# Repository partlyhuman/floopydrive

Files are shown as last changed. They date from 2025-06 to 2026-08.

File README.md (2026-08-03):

# the Floopy Drive 💕

This is a flashcart/devcart for the Casio Loopy. 

[☕️ Pre-built carts shipping worldwide on loopy.land/shop](https://loopy.land/shop)

[📖 User's Guide](https://github.com/partlyhuman/loopycart/wiki)

[YouTube<br>📺 Introductory Video](http://www.youtube.com/watch?v=_Q8cJwyDRfA)

To help find your way around:

* [pcb/flash-32mbit/](pcb/flash-32mbit/) The star of the show, the Floopy Drive PCB
* [flash-programmer/](flash-programmer/) Firmware that runs on the Floopy Drive, plus the PC interface for flashing it
* [cart-shell/](cart-shell/) 3D printable case for the Floopy Drive
* [labels/](labels/) Printable labels you can affix to a finished Floopy Drive
* [pcb/](pcb/) Other boards built along the way include a reverse-engineered cart that started it all
* [scans/](scans/) Scans of de-populated OEM Loopy games used as reference
* [data/](data/) Archive of relevant part datasheets for quick reference

Related repositories:

* [OSCR](https://github.com/sanni/cartreader) — I contributed a Casio Loopy adapter and code to the Open Source Cartridge Dumper, as well as a [makeshift adapter](https://github.com/sanni/cartreader/discussions/354#discussioncomment-10103848) that doesn't require an original cart connector
* [Loopy-Tools](https://github.com/kasamikona/Loopy-Tools) — a treasure trove of documentation and tooling around the Loopy by @kasamikona
* [Loopy-Schematics](https://github.com/kasamikona/Loopy-Schematics) - Schematics for various parts of, and accessories for, the Casio Loopy by @kasamikona
* [LoopyMSE](https://github.com/LoopyMSE/LoopyMSE) — an open-source cross-platform Loopy emulator created by @PSI-Rockin

### Contributors! 💕

None of this would be possible without the contributions of [@kasamikona](https://github.com/kasamikona) and [@kvanderlaag](https://github.com/kvanderlaag), with many, many additional thanks to the members of the [Unloved Budget Computer Hole](https://discord.gg/DH8cArK2) Discord server.

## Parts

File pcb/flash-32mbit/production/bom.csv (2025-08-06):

Designator | Footprint | Quantity | Value | LCSC Part #
BT1 | Keystone-3034TR-MFG | 1 | CR2032
C1 | 0805 | 1 | 1u
C2, C4, C5, C6, C7 | 0805 | 5 | 0.1u
D1 | SOT-23 | 1 | BAT54C
D2 | SOT-23-3 | 1 | PMEG4005CT,215
D3 | SOT-23 | 1 | BSS138
J1 | LOOPY_Cart_Edge | 1 | ~
R1, R13, R2, R6, R9 | 0805 | 5 | 1K
R10 | 0805 | 1 | 2K2
R11, R14, R3, R4, R5, R8 | 0805 | 6 | 100K
R12 | 0805 | 1 | 10K
U1 | TSOP-I-56_18.4x14mm_P0.5mm-HandSolder | 1 | LH28F320SKTD-L70
U2 | SOIC127P1410X300-32N | 1 | AS6C1008-55SIN
U3 | SOT-23-5 | 1 | SN74LVC1G04
U4 | RP2040-Tiny | 1 | RP2040-Tiny
U5, U6, U7 | SSOP-28_5.3x10.2mm_P0.65mm | 3 | MCP23S17T-E/SS

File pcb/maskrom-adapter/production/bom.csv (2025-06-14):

Designator | Footprint | Quantity | Value | LCSC Part #
IC1 | LOOPY-SOIC-44 | 1 | Maskrom
IC2 | SOP50P2000X120-48N | 1 | M29F160FB5AN6F2
R1 | 0805 | 1 | 1K

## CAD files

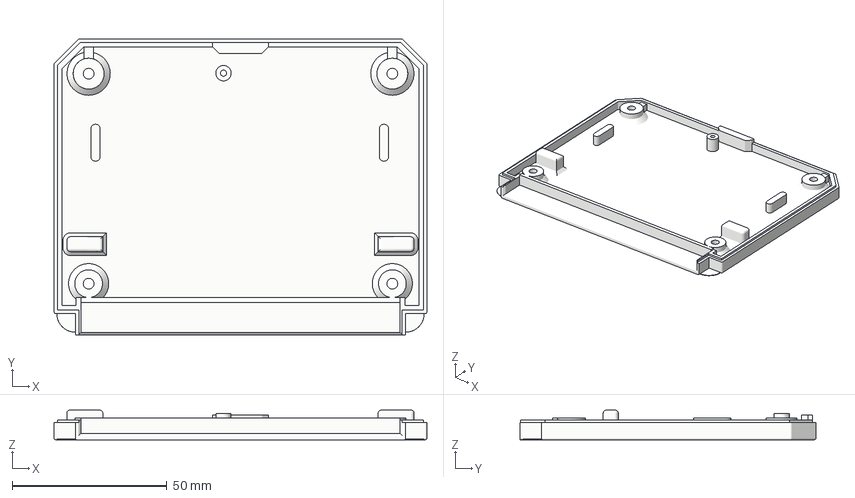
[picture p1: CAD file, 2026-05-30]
cart-shell/FloopyDrive-Rear.3mf
120.6 x 95.7 x 9.60 mm

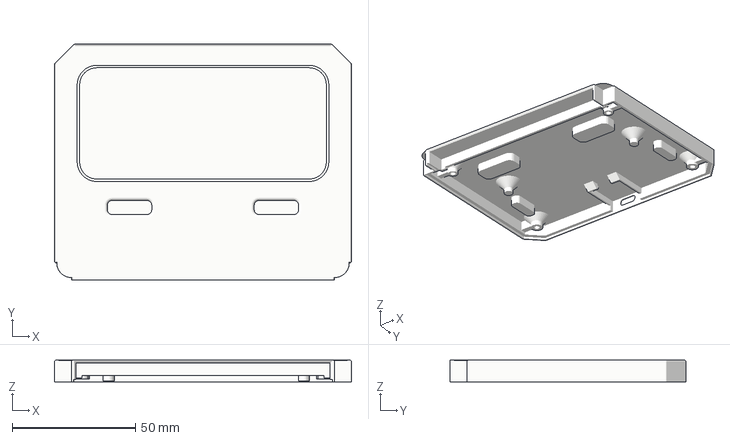
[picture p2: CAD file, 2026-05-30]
cart-shell/FloopyDrive-Front.3mf
120.6 x 95.7 x 8.85 mm

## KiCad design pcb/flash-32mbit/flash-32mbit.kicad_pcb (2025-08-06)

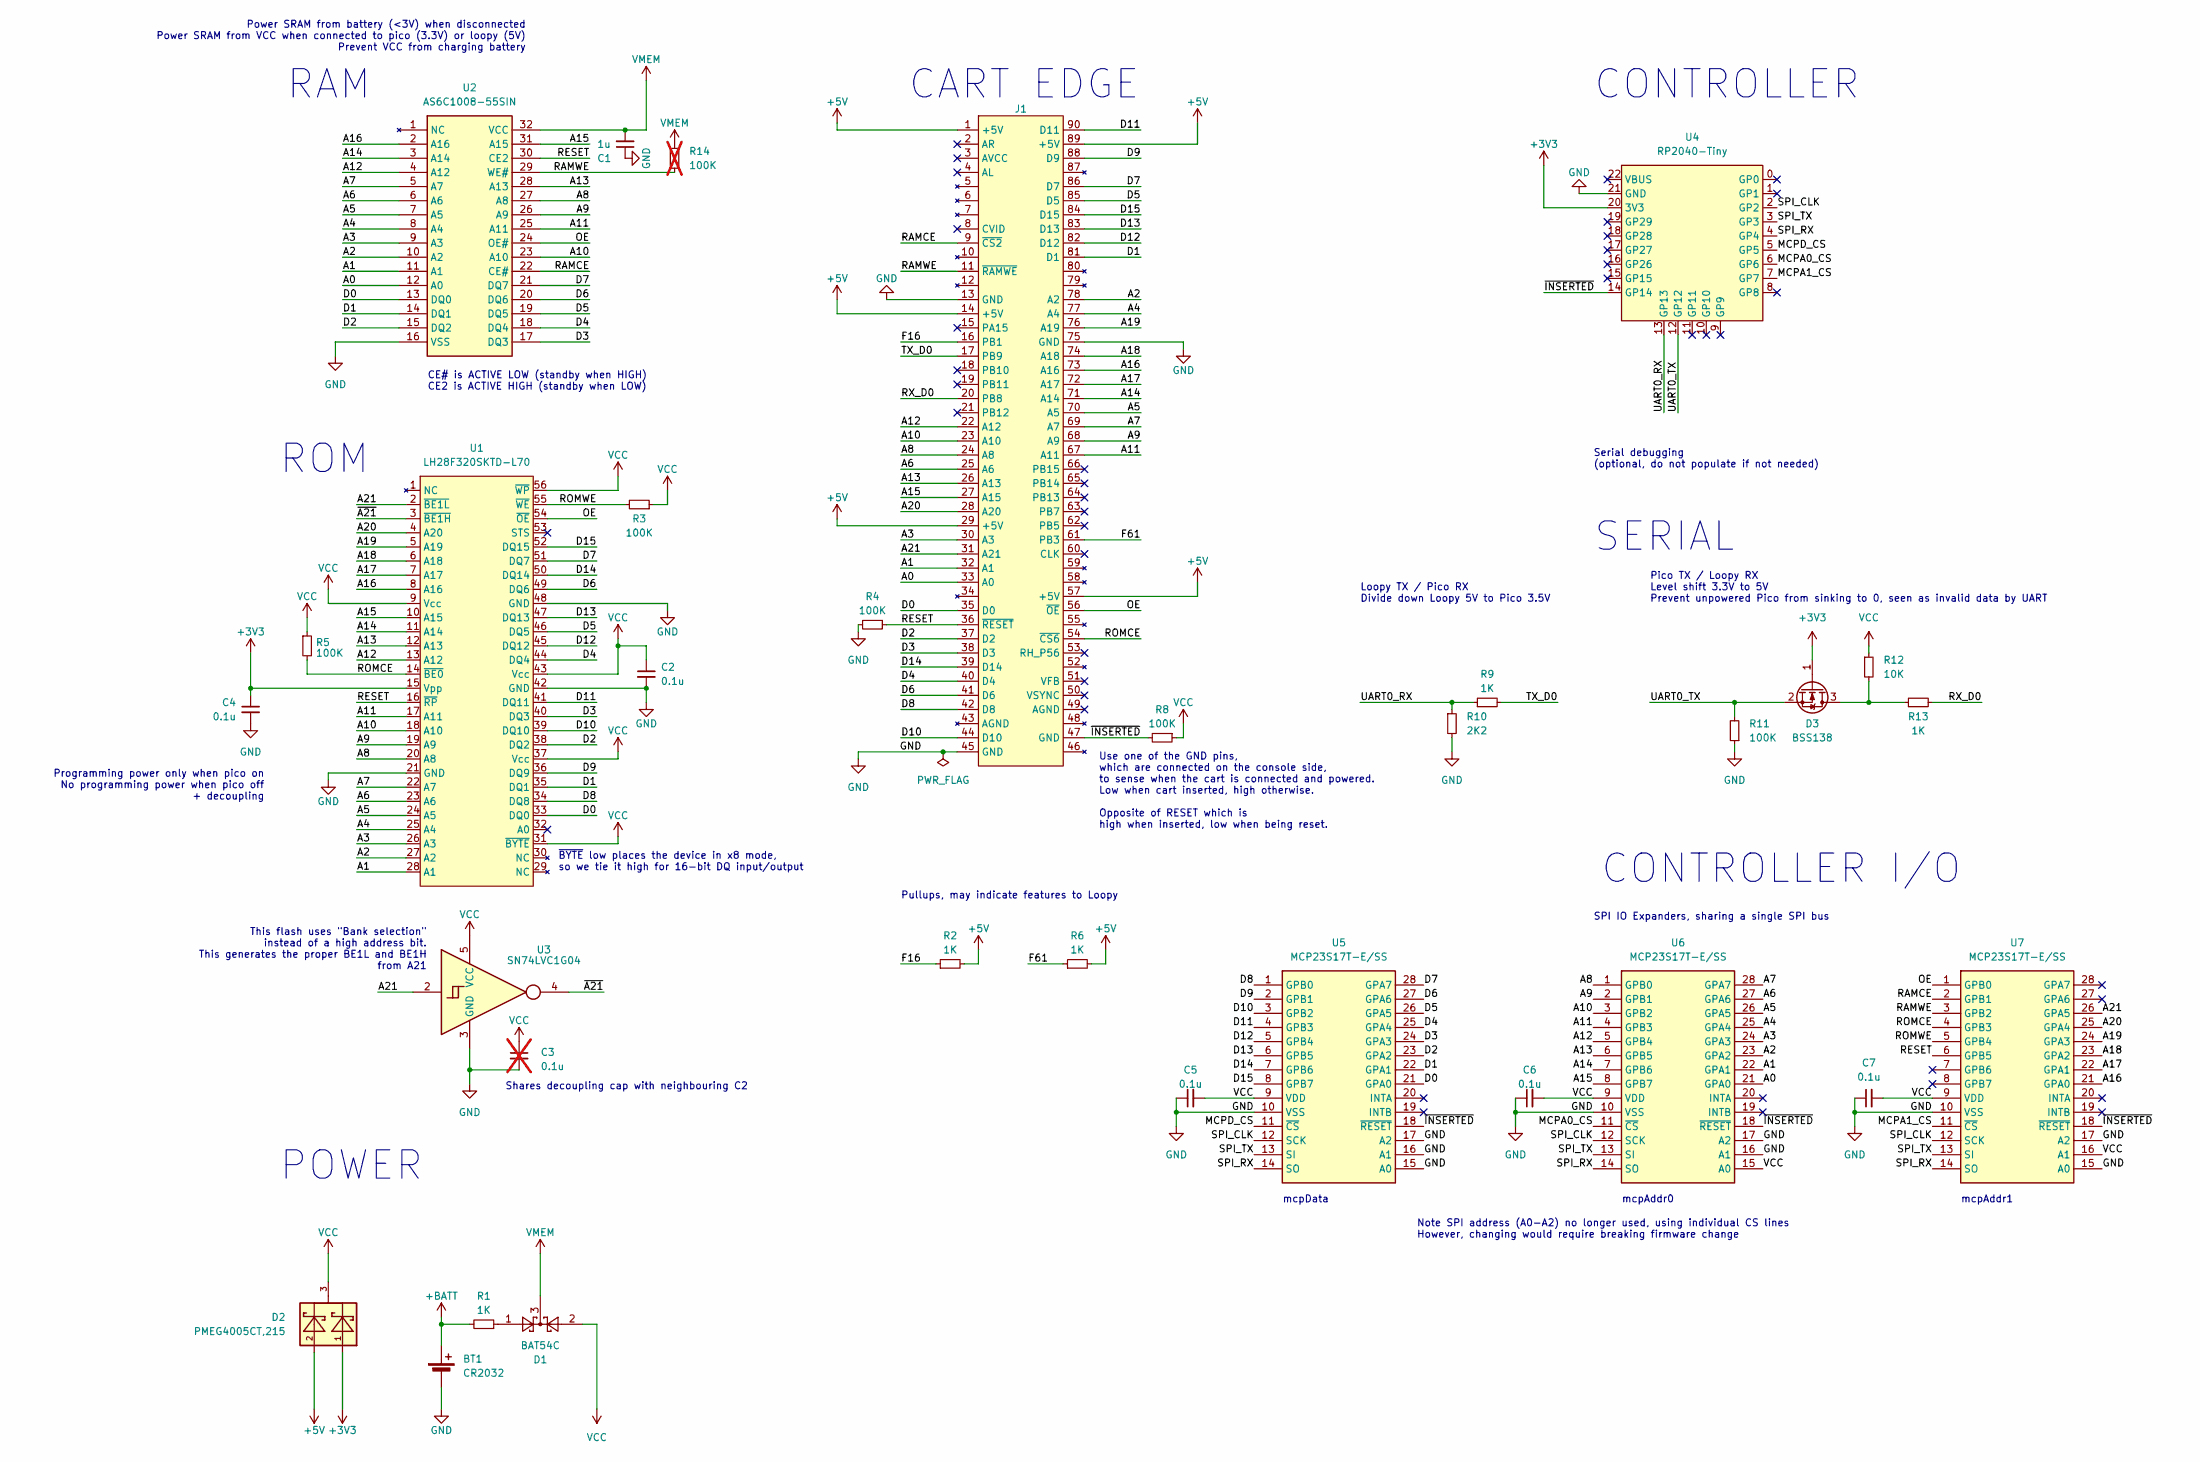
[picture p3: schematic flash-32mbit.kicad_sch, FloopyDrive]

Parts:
BT1: CR2032; Keystone-3034TR-MFG
C1: 1u; C_0805_2012Metric_Pad1.18x1.45mm_HandSolder
C2, C4, C5, C6, C7: 0.1u; C_0805_2012Metric_Pad1.18x1.45mm_HandSolder
C3: 0.1u; C_0805_2012Metric_Pad1.18x1.45mm_HandSolder; not fitted
D1: BAT54C; SOT-23
D2: PMEG4005CT,215; SOT-23-3
D3: BSS138; SOT-23
J1: LOOPY_Cart_Edge
R1, R2, R6, R9, R13: 1K; R_0805_2012Metric_Pad1.20x1.40mm_HandSolder
R3, R4, R5, R8, R11: 100K; R_0805_2012Metric_Pad1.20x1.40mm_HandSolder
R10: 2K2; R_0805_2012Metric_Pad1.20x1.40mm_HandSolder
R12: 10K; R_0805_2012Metric_Pad1.20x1.40mm_HandSolder
R14: 100K; R_0805_2012Metric_Pad1.20x1.40mm_HandSolder; not fitted
U1: LH28F320SKTD-L70; TSOP-I-56_18.4x14mm_P0.5mm-HandSolder
U2: AS6C1008-55SIN; SOIC127P1410X300-32N; Manufacturer_Part_Number AS6C1008-55SIN; Mouser Part Number 913-AS6C1008-55SIN
U3: SN74LVC1G04; SOT-23-5
U4: RP2040-Tiny
U5, U6, U7: MCP23S17T-E/SS; SSOP-28_5.3x10.2mm_P0.65mm; Manufacturer_Part_Number MCP23S17T-E/SO; Mouser Part Number 579-MCP23S17T-E/SO

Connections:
+3V3: C4.1, D2.1, D3.1 (G), U1.15 (Vpp), U4.20 (3V3)
+5V: D2.2, J1.1 (+5V), J1.14 (+5V), J1.29 (+5V), J1.57 (+5V), J1.89 (+5V), R2.2, R6.2
+BATT: BT1.1 (+), R1.2
/A0: J1.33 (A0), U2.12 (A0), U6.21 (GPA0)
/A1: J1.32 (A1), U1.28 (A1), U2.11 (A1), U6.22 (GPA1)
/A2: J1.78 (A2), U1.27 (A2), U2.10 (A2), U6.23 (GPA2)
/A3: J1.30 (A3), U1.26 (A3), U2.9 (A3), U6.24 (GPA3)
/A4: J1.77 (A4), U1.25 (A4), U2.8 (A4), U6.25 (GPA4)
/A5: J1.70 (A5), U1.24 (A5), U2.7 (A5), U6.26 (GPA5)
/A6: J1.25 (A6), U1.23 (A6), U2.6 (A6), U6.27 (GPA6)
/A7: J1.69 (A7), U1.22 (A7), U2.5 (A7), U6.28 (GPA7)
/A8: J1.24 (A8), U1.20 (A8), U2.27 (A8), U6.1 (GPB0)
/A9: J1.68 (A9), U1.19 (A9), U2.26 (A9), U6.2 (GPB1)
/A10: J1.23 (A10), U1.18 (A10), U2.23 (A10), U6.3 (GPB2)
/A11: J1.67 (A11), U1.17 (A11), U2.25 (A11), U6.4 (GPB3)
/A12: J1.22 (A12), U1.13 (A12), U2.4 (A12), U6.5 (GPB4)
/A13: J1.26 (A13), U1.12 (A13), U2.28 (A13), U6.6 (GPB5)
/A14: J1.71 (A14), U1.11 (A14), U2.3 (A14), U6.7 (GPB6)
/A15: J1.27 (A15), U1.10 (A15), U2.31 (A15), U6.8 (GPB7)
/A16: J1.73 (A16), U1.8 (A16), U2.2 (A16), U7.21 (GPA0)
/A17: J1.72 (A17), U1.7 (A17), U7.22 (GPA1)
/A18: J1.74 (A18), U1.6 (A18), U7.23 (GPA2)
/A19: J1.76 (A19), U1.5 (A19), U7.24 (GPA3)
/A20: J1.28 (A20), U1.4 (A20), U7.25 (GPA4)
/A21: J1.31 (A21), U1.2 (~BE1L), U3.2, U7.26 (GPA5)
/D0: J1.35 (D0), U1.33 (DQ0), U2.13 (DQ0), U5.21 (GPA0)
/D1: J1.81 (D1), U1.35 (DQ1), U2.14 (DQ1), U5.22 (GPA1)
/D2: J1.37 (D2), U1.38 (DQ2), U2.15 (DQ2), U5.23 (GPA2)
/D3: J1.38 (D3), U1.40 (DQ3), U2.17 (DQ3), U5.24 (GPA3)
/D4: J1.40 (D4), U1.44 (DQ4), U2.18 (DQ4), U5.25 (GPA4)
/D5: J1.85 (D5), U1.46 (DQ5), U2.19 (DQ5), U5.26 (GPA5)
/D6: J1.41 (D6), U1.49 (DQ6), U2.20 (DQ6), U5.27 (GPA6)
/D7: J1.86 (D7), U1.51 (DQ7), U2.21 (DQ7), U5.28 (GPA7)
/D8: J1.42 (D8), U1.34 (DQ8), U5.1 (GPB0)
/D9: J1.88 (D9), U1.36 (DQ9), U5.2 (GPB1)
/D10: J1.44 (D10), U1.39 (DQ10), U5.3 (GPB2)
/D11: J1.90 (D11), U1.41 (DQ11), U5.4 (GPB3)
/D12: J1.82 (D12), U1.45 (DQ12), U5.5 (GPB4)
/D13: J1.83 (D13), U1.47 (DQ13), U5.6 (GPB5)
/D14: J1.39 (D14), U1.50 (DQ14), U5.7 (GPB6)
/D15: J1.84 (D15), U1.52 (DQ15), U5.8 (GPB7)
/F16: J1.16 (PB1), R2.1
/F61: J1.61 (PB3), R6.1
/MCPA0_CS: U4.6 (GP6), U6.11 (~CS)
/MCPA1_CS: U4.7 (GP7), U7.11 (~CS)
/MCPD_CS: U4.5 (GP5), U5.11 (~CS)
/OE: J1.56 (~OE), U1.54 (~OE), U2.24 (OE#), U7.1 (GPB0)
/RAMCE: J1.9 (~CS2), U2.22 (CE#), U7.2 (GPB1)
/RAMWE: J1.11 (~RAMWE), R14.2, U2.29 (WE#), U7.3 (GPB2)
/RESET: J1.36 (~RESET), R4.1, U1.16 (~RP), U2.30 (CE2), U7.6 (GPB5)
/ROMCE: J1.54 (~CS6), R5.2, U1.14 (~BE0), U7.4 (GPB3)
/ROMWE: R3.2, U1.55 (~WE), U7.5 (GPB4)
/RX_D0: J1.20 (PB8), R13.2
/SPI_CLK: U4.2 (GP2), U5.12 (SCK), U6.12 (SCK), U7.12 (SCK)
/SPI_RX: U4.4 (GP4), U5.14 (SO), U6.14 (SO), U7.14 (SO)
/SPI_TX: U4.3 (GP3), U5.13 (SI), U6.13 (SI), U7.13 (SI)
/TX_D0: J1.17 (PB9), R9.2
/UART0_RX: R9.1, R10.1, U4.13 (GP13)
/UART0_TX: D3.2 (S), R11.2, U4.12 (GP12)
/~A21: U1.3 (~BE1H), U3.4
/~INSERTED: J1.47 (GND), R8.2, U4.14 (GP14), U5.18 (~RESET), U6.18 (~RESET), U7.18 (~RESET)
GND: BT1.2 (-), C1.1, C2.2, C3.2, C4.2, C5.1, C6.1, C7.1, J1.13 (GND), J1.45 (GND), J1.75 (GND), R4.2, R10.2, R11.1, U1.21 (GND), U1.42 (GND), U1.48 (GND), U2.16 (VSS), U3.3 (GND), U4.21 (GND), U5.10 (VSS), U5.15 (A0), U5.16 (A1), U5.17 (A2), U6.10 (VSS), U6.16 (A1), U6.17 (A2), U7.10 (VSS), U7.15 (A0), U7.17 (A2)
unnamed: D1.1, R1.1
unnamed: D3.3 (D), R12.2, R13.1
VCC: C2.1, C3.1, C5.2, C6.2, C7.2, D1.2, D2.3, R3.1, R5.1, R8.1, R12.1, U1.9 (Vcc), U1.31 (~BYTE), U1.37 (Vcc), U1.43 (Vcc), U1.56 (~WP), U3.5 (VCC), U5.9 (VDD), U6.9 (VDD), U6.15 (A0), U7.9 (VDD), U7.16 (A1)
VMEM: C1.2, D1.3, R14.1, U2.32 (VCC)

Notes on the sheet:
Use one of the GND pins, which are connected on the console side, to sense when the cart is connected and powered. Low when cart inserted, high otherwise. Opposite of RESET which is high when inserted, low when being reset.
Power SRAM from battery (<3V) when disconnected Power SRAM from VCC when connected to pico (3.3V) or loopy (5V) Prevent VCC from charging battery
POWER
RAM
Shares decoupling cap with neighbouring C2
ROM
Loopy TX / Pico RX Divide down Loopy 5V to Pico 3.5V
CE# is ACTIVE LOW (standby when HIGH) CE2 is ACTIVE HIGH (standby when LOW)
Note SPI address (A0-A2) no longer used, using individual CS lines However, changing would require breaking firmware change
CART EDGE
mcpAddr0
mcpAddr1
This flash uses "Bank selection" instead of a high address bit. This generates the proper BE1L and BE1H from A21
Programming power only when pico on No programming power when pico off + decoupling
Pullups, may indicate features to Loopy
Serial debugging (optional, do not populate if not needed)
Pico TX / Loopy RX Level shift 3.3V to 5V Prevent unpowered Pico from sinking to 0, seen as invalid data by UART
SERIAL
SPI IO Expanders, sharing a single SPI bus
~{BYTE} low places the device in x8 mode, so we tie it high for 16-bit DQ input/output
CONTROLLER
CONTROLLER I/O
mcpData

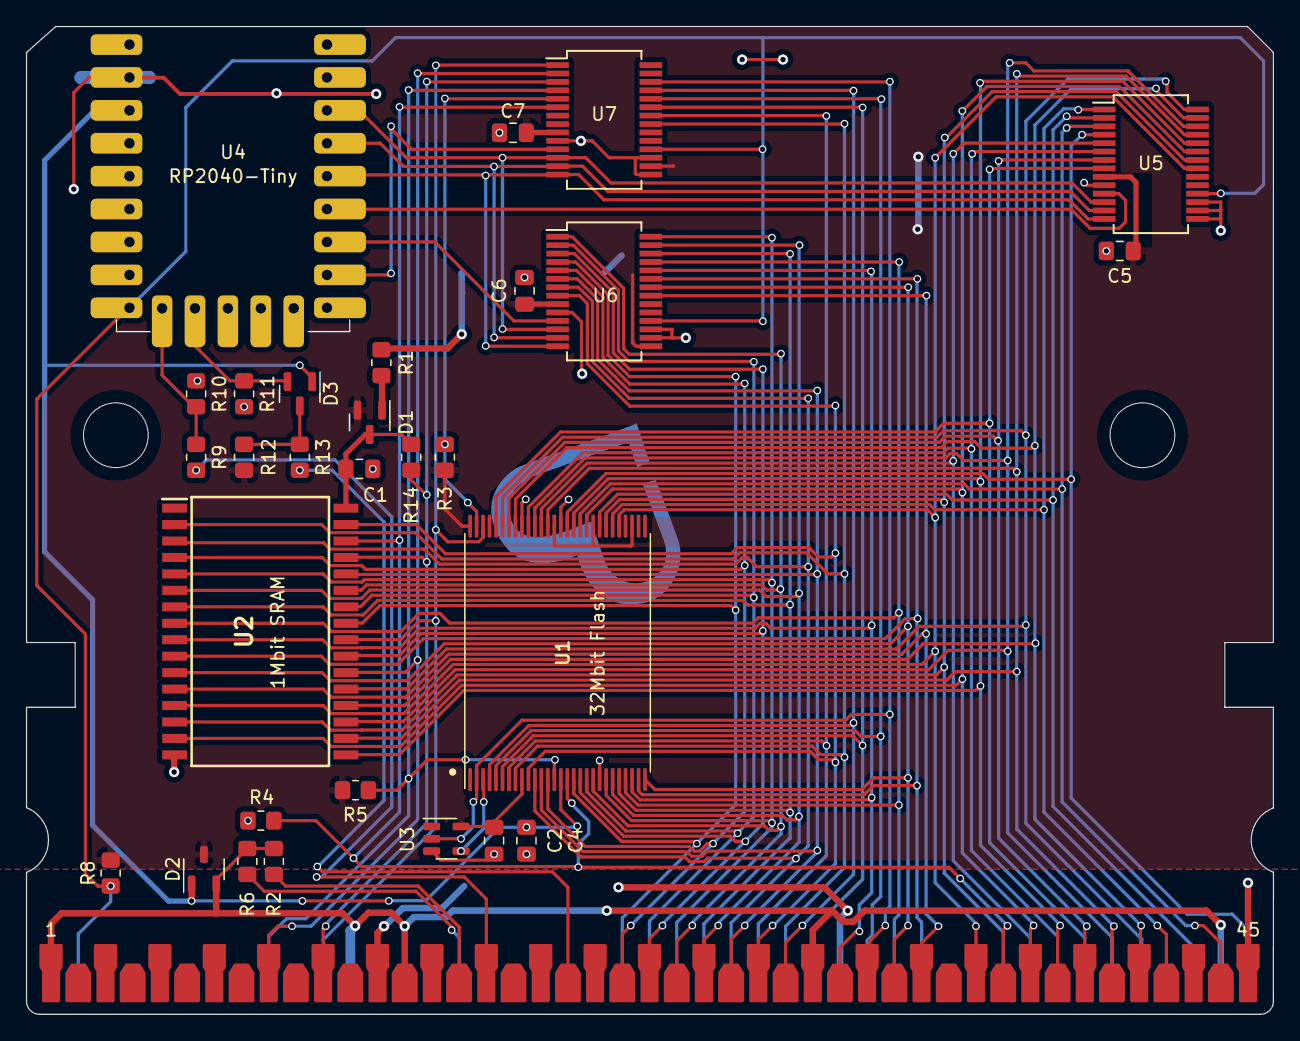
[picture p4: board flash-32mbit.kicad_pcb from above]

Board: 2 copper layers, 96.3 x 76.2 mm, 33 parts (1 on the bottom side), 66 nets.

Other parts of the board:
H1, H2: MountingHole_5mm

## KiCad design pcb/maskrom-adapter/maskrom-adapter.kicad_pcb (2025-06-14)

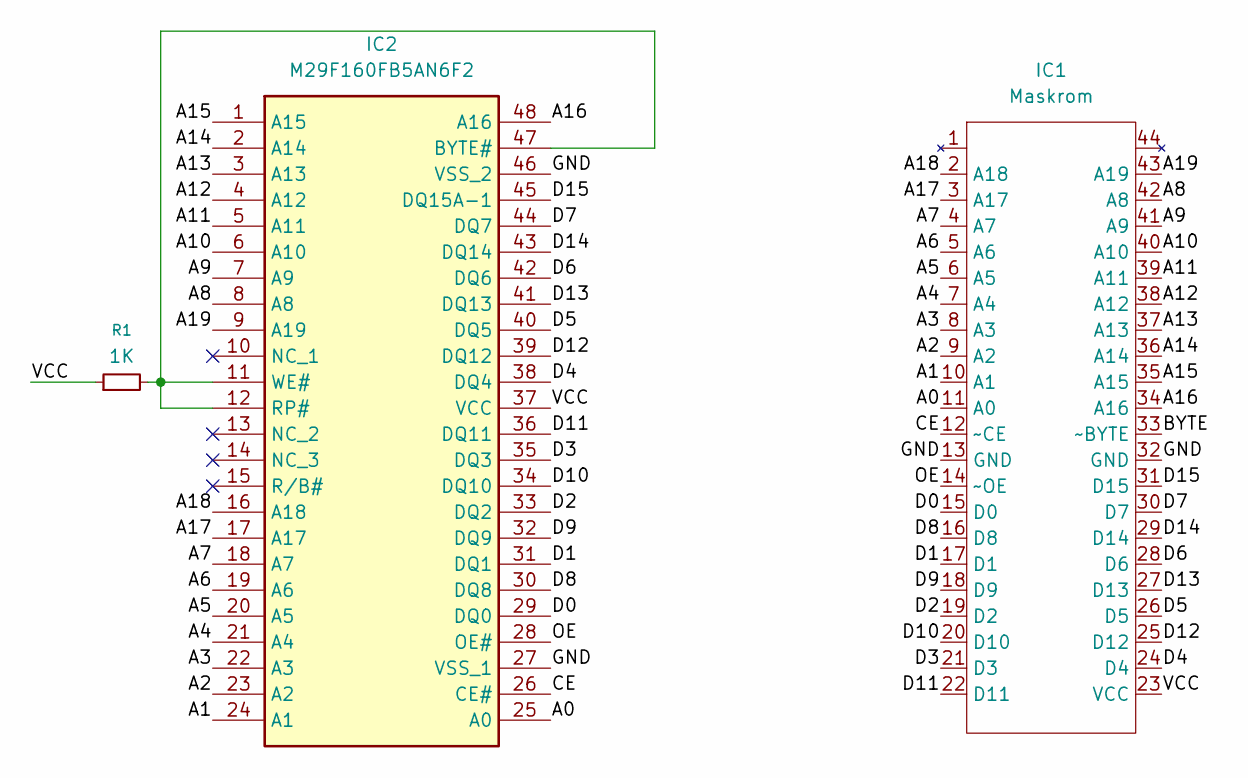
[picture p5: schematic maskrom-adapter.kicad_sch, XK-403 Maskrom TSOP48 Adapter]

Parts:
IC1: Maskrom; LOOPY-SOIC-44
IC2: M29F160FB5AN6F2; SOP50P2000X120-48N; Manufacturer_Part_Number M29F160FB5AN6F2; Mouser Part Number 913-M29F160FB5AN6F2
R1: 1K; LED_0805_2012Metric_Pad1.15x1.40mm_HandSolder

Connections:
/A0: IC1.11 (A0), IC2.25 (A0)
/A1: IC1.10 (A1), IC2.24 (A1)
/A2: IC1.9 (A2), IC2.23 (A2)
/A3: IC1.8 (A3), IC2.22 (A3)
/A4: IC1.7 (A4), IC2.21 (A4)
/A5: IC1.6 (A5), IC2.20 (A5)
/A6: IC1.5 (A6), IC2.19 (A6)
/A7: IC1.4 (A7), IC2.18 (A7)
/A8: IC1.42 (A8), IC2.8 (A8)
/A9: IC1.41 (A9), IC2.7 (A9)
/A10: IC1.40 (A10), IC2.6 (A10)
/A11: IC1.39 (A11), IC2.5 (A11)
/A12: IC1.38 (A12), IC2.4 (A12)
/A13: IC1.37 (A13), IC2.3 (A13)
/A14: IC1.36 (A14), IC2.2 (A14)
/A15: IC1.35 (A15), IC2.1 (A15)
/A16: IC1.34 (A16), IC2.48 (A16)
/A17: IC1.3 (A17), IC2.17 (A17)
/A18: IC1.2 (A18), IC2.16 (A18)
/A19: IC1.43 (A19), IC2.9 (A19)
/BYTE: IC1.33 (~BYTE)
/CE: IC1.12 (~CE), IC2.26 (CE#)
/D0: IC1.15 (D0), IC2.29 (DQ0)
/D1: IC1.17 (D1), IC2.31 (DQ1)
/D2: IC1.19 (D2), IC2.33 (DQ2)
/D3: IC1.21 (D3), IC2.35 (DQ3)
/D4: IC1.24 (D4), IC2.38 (DQ4)
/D5: IC1.26 (D5), IC2.40 (DQ5)
/D6: IC1.28 (D6), IC2.42 (DQ6)
/D7: IC1.30 (D7), IC2.44 (DQ7)
/D8: IC1.16 (D8), IC2.30 (DQ8)
/D9: IC1.18 (D9), IC2.32 (DQ9)
/D10: IC1.20 (D10), IC2.34 (DQ10)
/D11: IC1.22 (D11), IC2.36 (DQ11)
/D12: IC1.25 (D12), IC2.39 (DQ12)
/D13: IC1.27 (D13), IC2.41 (DQ13)
/D14: IC1.29 (D14), IC2.43 (DQ14)
/D15: IC1.31 (D15), IC2.45 (DQ15A-1)
/GND: IC1.13 (GND), IC1.32 (GND), IC2.27 (VSS_1), IC2.46 (VSS_2)
/OE: IC1.14 (~OE), IC2.28 (OE#)
/VCC: IC1.23 (VCC), IC2.37 (VCC), R1.1
unnamed: IC2.11 (WE#), IC2.12 (RP#), IC2.47 (BYTE#), R1.2

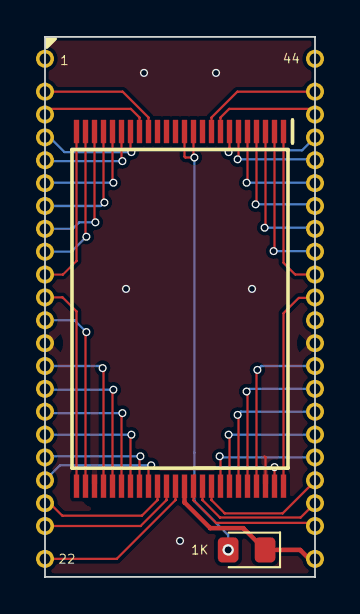
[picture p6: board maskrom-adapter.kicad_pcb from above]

Board: 2 copper layers, 15.0 x 30.0 mm, 3 parts (0 on the bottom side), 41 nets.

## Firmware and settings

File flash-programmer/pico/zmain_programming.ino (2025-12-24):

#define ABORT_AFTER_MS 1000

// Keep Adafruit VID, custom PID for programming
#define VID_PROG 0x239A
#define PID_PROG 0xF100

static int bootErrors = 0;

void onSuccess(bool echoOk = true) {
  if (echoOk) echo_ok();
  setControl(IDLE);
  ledColor(0);
}

void loop_programming() {
  static uint8_t buf[USB_BUFSIZE];
  static bool isProgrammingFlash = false;
  static bool isProgrammingSram = false;
  static uint32_t addr = 0;
  static uint32_t totalBytes;
  static uint32_t idleSince = 0;


  if (!usb_web.available()) {
    // DEBUGGING idle detect shows the pico is still looping if other things have halted due to error
    if (idleSince == 0) {
      idleSince = millis();
    } else if (millis() - idleSince > ABORT_AFTER_MS) {
      if (isProgrammingFlash || isProgrammingSram) {
        isProgrammingFlash = false;
        isProgrammingSram = false;
        echo_all("!ERROR Aborted programming after no data\r\n");
      }
    }
    return;
  }
  idleSince = 0;

  size_t bufLen = usb_web.read(buf, USB_BUFSIZE);

  if (isProgrammingFlash) {
    isProgrammingFlash = flashWriteBuffer(buf, bufLen, addr, totalBytes);
    if (!isProgrammingFlash) onSuccess();
    return;
  } else if (isProgrammingSram) {
    isProgrammingSram = sramWriteBuffer(buf, bufLen, addr, totalBytes);
    if (!isProgrammingSram) onSuccess();
    return;
  }

  else if (buf[0] == 'E') {
    // ERASE COMMAND
    if (buf[1] == '\r') {
      ledColor(BLUE);
      flashCommand(0, CMD_RESET);
      delay(100);
      flashClearLocks();
      delay(100);
      flashCommand(0, CMD_RESET);
      delay(100);
      flashEraseAll();
      delay(100);
      flashCommand(0, CMD_RESET);
      onSuccess();
    } else if (buf[1] == 's' && buf[2] == '\r') {
      ledColor(BLUE);
      sramErase();
      onSuccess();
    } else if (buf[1] == '0' && buf[2] == '\r') {
      // DEPRECATED
      ledColor(BLUE);
      flashEraseBank(0);
      flashCommand(0, CMD_RESET);
      onSuccess();
    } else if (buf[1] == '1' && buf[2] == '\r') {
      // DEPRECATED
      ledColor(BLUE);
      flashEraseBank(1);
      flashCommand(0, CMD_RESET);
      onSuccess();
    } else if (sscanf((char *)buf, "E%ld\r", &totalBytes) && totalBytes > 0 && totalBytes <= FLASH_SIZE) {
      stopwatch = millis();
      sprintf(S, "Erasing %d bytes of flash up to %06xh\r\n", totalBytes, totalBytes);
      echo_all();
      ledColor(BLUE);
      for (addr = 0; addr < totalBytes; addr += FLASH_BLOCK_SIZE) {
        sprintf(S, "%06xh ", addr);
        echo_all();
        if (!flashEraseBlock(addr)) {
          echo_all("\r\n!ERR ABORTING ERASE\r\n");
          return;
        }
      }
      // // NOTE: Erasing by bank isn't faster than erasing by block, so this adds complexity but saves no time
      // addr = 0;
      // while (addr < totalBytes) {
      //   sprintf(S, "%06xh ", addr);
      //   echo_all();
      //   if (addr == 0 && totalBytes >= FLASH_BANK_SIZE) {
      //     flashEraseBank(0);
      //     addr += FLASH_BANK_SIZE;
      //   } else if (addr == FLASH_BANK_SIZE && totalBytes == FLASH_BANK_SIZE * 2) {
      //     flashEraseBank(1);
      //     addr += FLASH_BANK_SIZE;
      //   } else {
      //     if (!flashEraseBlock(addr)) {
      //       echo_all("\r\n!ERR ABORTING ERASE\r\n");
      //       return;
      //     }
      //   }
      // }
      sprintf(S, "\r\nErased %d bytes in %0.2f sec using block erasing\r\n", addr, (millis() - stopwatch) / 1000.0);
      echo_all();
      onSuccess();
    }
  }

  else if (buf[0] == 'I' && buf[1] == '\r') {
    // INSPECT COMMAND
    // flashId();
    echo_all("\r\n---CART-ID---\r\n");
    sprintf(S, "Cart header %s\r\n", flashCartHeaderCheck() ? "OK" : "NOT OK");
    echo_all();
    sprintf(S, "Cart ID %08x\r\n", flashCartHeaderId());
    echo_all();
    echo_all("\r\n---FLASH-lower---\r\n");
    flashInspect(0x000000, 0x000100);
    echo_all("\r\n------\r\n");
    flashInspect(0x100000, 0x100100);
    echo_all("\r\n---FLASH-upper---\r\n");
    flashInspect(0x200000, FLASH_BANK_SIZE + 0x000100);
    echo_all("\r\n------\r\n");
    flashInspect(0x300000, FLASH_BANK_SIZE + 0x100100);
    echo_all("\r\n---SRAM---\r\n");
    sramInspect(0, 0x100);
    echo_all("\r\n---FILESYSTEM---\r\n");
    Dir dir = LittleFS.openDir("/");
    while (dir.next()) {
      echo_all(dir.fileName().c_str());
      echo_all("\r\n");
    }

    // Some info in the info64 struct comes out as zeroes
    // FSInfo64 info;
    // LittleFS.info64(info);
    FSInfo info;
    LittleFS.info(info);
    sprintf(S, "%d/%d bytes used, %0.0f%% full\r\n", info.usedBytes, info.totalBytes, 100.0 * (info.usedBytes + 0.0) / info.totalBytes);
    echo_all();
    onSuccess();
  }

  else if (buf[0] == 'D') {
    // DUMP COMMAND
    if (2 == sscanf((char *)buf, "D%ld/%ld\r", &addr, &totalBytes)) {
      // followed by start address and total # of bytes
      if (addr > 0 && totalBytes > 0 && totalBytes <= FLASH_SIZE) {
        ledColor(BLUE);
        flashDump(addr, addr + totalBytes);
        onSuccess(false);
      } else {
        ledColor(RED);
      }
    } else if (1 == sscanf((char *)buf, "D%ld\r", &totalBytes)) {
      // followed by expected # of bytes
      if (totalBytes > 0 && totalBytes <= FLASH_SIZE) {
        ledColor(BLUE);
        flashDump(0, totalBytes);
        onSuccess(false);
      } else {
        ledColor(RED);
      }
    } else if (buf[1] == 's' && buf[2] == '\r') {
      sramDump();
      onSuccess(false);
    }
  }

  else if (buf[0] == 'P') {
    // PROGRAM COMMAND
    if (1 == sscanf((char *)buf, "P%ld\r", &totalBytes) && totalBytes > 0 && totalBytes <= FLASH_SIZE) {
      // program flash followed by expected # of bytes
      sprintf(S, "Programming %d bytes to flash\r", totalBytes);
      echo_all();
      isProgrammingFlash = true;
      addr = 0;
      stopwatch = millis();
      ledColor(BLUE);
    } else if (1 == sscanf((char *)buf, "Ps%ld\r", &totalBytes) && totalBytes > 0 && totalBytes <= SRAM_SIZE) {
      // program SRAM followed by expected # of bytes
      sprintf(S, "Programming %d bytes to SRAM\r", totalBytes);
      echo_all();
      isProgrammingSram = true;
      addr = 0;
      stopwatch = millis();
      ledColor(BLUE);
    }
  }

  else if (buf[0] == 'S') {
    // SRAM BACKUP & RESTORE FROM FILESYSTEM

    // ID the header
    uint32_t cartId = flashCartHeaderId();

    // we always use <crc32>.sav which is 8 1 3 = 12 chars plus string terminator = 13 bytes
    const size_t SAVE_FILENAME_LEN = 13;
    char filename[SAVE_FILENAME_LEN];
    sprintf(filename, "%08x.sav", cartId);

    if (buf[1] == 'r' && buf[2] == '\r') {
      // backup SRAM to file
      uint32_t sramSize = min(flashCartHeaderSramSize(), SRAM_SIZE);
      sprintf(S, "Backing up first %d bytes of SRAM to %s\r\n", sramSize, filename);
      echo_all();
      ledColor(BLUE);
      sramSaveFile(filename, sramSize);
      onSuccess();
    } else if (buf[1] == 'w' && buf[2] == '\r') {
      // restore SRAM from file
      sprintf(S, "Restoring SRAM contents from %s\r\n", filename);
      echo_all();
      uint32_t sramSize = min(flashCartHeaderSramSize(), SRAM_SIZE);
      ledColor(BLUE);
      sramLoadFile(filename) || sramErase(sramSize);
      onSuccess();
    } else if (buf[1] == 'f' && buf[2] == '\r') {
      // Clear filesystem!
      echo_all("Clearing all save states stored on Floopy Drive!!\r\n");
      ledColor(BLUE);
      LittleFS.format();
      onSuccess();
    }
  }

  else if (buf[0] == 'N') {
    // SET NICKNAME
    if (sscanf((char *)buf, "N%[^\r]\r", S) && strlen(S) > 0) {
      setNickname(S);
      onSuccess();
    } else {
      setNickname(NULL);
      onSuccess();
    }
  }

  else if (buf[0] == 'O' && buf[1] == 'C') {
    // MODIFY SPI OVERCLOCK
    long newSpiClock;
    if (buf[2] == '+') {
      newSpiClock = SPI_OC2_UNSTABLE;
    } else if (buf[2] == '-') {
      newSpiClock = SPI_OC0;
    } else if (sscanf((char *)buf, "OC%ld\r", &newSpiClock) && newSpiClock > MHZ) {
    } else {
      newSpiClock = SPI_OC1_TESTED;
    }
    mcpSetSpiClock(newSpiClock);
    sprintf(S, "Set SPI clock speed to %d MHz\r\n", newSpiClock / MHZ);
    echo_all();
    if (newSpiClock >= SPI_OC2_UNSTABLE) {
      echo_all("WARNING: This clock speed is beyond tested stable speeds.\r\n");
      echo_all("if you experience issues, disconnect your Floopy Drive.\r\n");
    }
  }

  else if (buf[0] != '\r') {
    // Received unknown command OR it's possible we returned to idle state before the sender was done sending?
    echo_all("Unrecognized command\r\n");
    ledColor(0xce4e04);  // orange
  }
}

void onUsbConnect(bool connected) {
  if (connected) {
    char connectStr[USB_BUFSIZE];
    for (int i = 0; i < USB_BUFSIZE; i++) {
      connectStr[i] = '\r';  // make printable
    }
    // Spit out firmware and hardware revisions first thing on connect
    // Ensure we append existing string buffer S which contains any preexisting boot logging
    sprintf(connectStr, "!FW %s\r\n!HW %d\r\n", GIT_COMMIT, HW_REVISION);
    usb_web.write((uint8_t *)connectStr, USB_BUFSIZE);
    usb_web.flush();

    if (bootErrors > 0) {
      echo_all();
      echo_all("\r\n!ERR boot log errors found above\r\n");
    }
  }
}

inline void bootError(const char *str, uint32_t ledErrorColor = 0x800000) {
  bootErrors++;
  sprintf(S, "%s %s", S, str);
  ledColor(ledErrorColor);
}

void setup_programming() {
  // Serial allows us to more easily reset/reprogram the Pico
  // In production, consider reworking echo_all and removing this?
  Serial.begin(115200);

  // Filesystem. Auto formats. Make sure to reserve size in Tools > Flash Size
  // If we wanted to customize the block size could use something like this modifying 4096, perhaps down to 1024
  // FS LittleFS = FS(FSImplPtr(new littlefs_impl::LittleFSImpl(&_FS_start, &_FS_end - &_FS_start, 256, 4096, 16)));
  if (!LittleFS.begin()) bootError("littleFS fail");

  // USB setup
  TinyUSBDevice.setID(VID_PROG, PID_PROG);
  // Reads nickname from FS, must place after LittleFS.begin
  const char *deviceName = makeNicknamedDeviceName();
  TinyUSBDevice.setProductDescriptor(deviceName);
  usb_web.setLandingPage(&landingPage);
  usb_web.setLineStateCallback(onUsbConnect);
  usb_web.setStringDescriptor(deviceName);
  usb_web.begin();

  // Setup IO expanders
  SPI.begin();
  if (!mcpAddr0.Init()) bootError("mcpAddr0 fail");
  if (!mcpAddr1.Init()) bootError("mcpAddr1 fail");
  if (!mcpData.Init()) bootError("mcpData fail");
  mcpSetSpiClock(SPI_OC1_TESTED);

  ioWriteMode(&mcpData);
  ioWriteMode(&mcpAddr0);

  // CAREFUL what happens when some of these active-low control lines are set momentarily
  busIdle();
  ioWriteMode(&mcpAddr1);
  busIdle();

  // DON'T Backup SRAM contents whenever Pico is booted up - this would ruin things when changing batteries
  // if (!bootErrors && flashCartHeaderCheck()) {
  //   uint32_t cartId = flashCartHeaderId();
  //   if (cartId != 0 && cartId != 0xffffffff) {
  //     ledColor(BLUE);
  //     const size_t SAVE_FILENAME_LEN = 13;
  //     char filename[SAVE_FILENAME_LEN];
  //     sprintf(filename, "%08x.sav", cartId);
  //     sramSaveFile(filename, min(flashCartHeaderSramSize(), SRAM_SIZE));
  //     ledColor(0);
  //   }
  // }

  // Clear flash lock bits preemptively whenever Pico is booted up
  if (!bootErrors) {
    flashClearLocks();
  }

  // Let either claim the USB
  while (!TinyUSBDevice.mounted() && !Serial) {
    delay(1);
  }

  if (!bootErrors) {
    // Give a little flash to indicate boot and connection ok, otherwise leave error status LED unchanged
    ledColor(0xff0000);
    delay(50);
    ledColor(0x00ff00);
    delay(50);
    ledColor(0x0000ff);
    delay(50);
    ledColor(0);
  }
}

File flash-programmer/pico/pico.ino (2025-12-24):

// ARDUINO BUILD SETTINGS
//   Earle Philhower Arduino-Pico core (board manager: https://github.com/earlephilhower/arduino-pico/releases/download/global/package_rp2040_index.json)
//   Waveshare RP2040 Zero (actual hardware is RP2040 Tiny)
//   Flash Size: 2MB (Sketch: 1MB, FS: 1MB)
//   CPU Speed: 300 MHz (Overclock)
//   Optimize: Optimize More (-O2)
//   USB Stack: Adafruit TinyUSB

#include <SPI.h>
#include <Adafruit_TinyUSB.h>
#include <Adafruit_NeoPixel.h>
#include <LittleFS.h>
#include <MCP23S17.h>  // MCP23017_WE library https://docs.arduino.cc/libraries/mcp23017_we/
#include "generated.h"

#define HW_REVISION 8

#undef DEBUG_LED

// Delays one clock cycle or 7ns @ 133MhZ = 0.000000007518797sec = 7.518797ns
// #define NOP 
#define NOP asm volatile("nop")
#define HALT while (true)

#define ADDRBITS 22
// 64kb blocks
#define FLASH_BLOCK_SIZE 0x010000
// two 2mb banks
#define FLASH_BANK_SIZE 0x200000
#define FLASH_SIZE FLASH_BANK_SIZE << 1
#define CMD_RESET 0xff
#define CMD_STATUS_CLR 0x50
#define PIN_INSERTED 14
#define USB_BUFSIZE 64

WEBUSB_URL_DEF(landingPage, 1, "f.loopy.land");
Adafruit_USBD_WebUSB usb_web;

// ~RESET is pulled high when pico is powered up, >=99 means dummy reset pin
#define MCP_NO_RESET_PIN 100
// SPI addresses for MCP23017 are: 0 1 0 0 A2 A1 A0
// Note we almost certainly don't need differing addresses any more since REV6 gave each a unique CE, but no harm keeping it
#define MCP_ADDR_DATA 32
#define MCP_ADDR_ADDR0 33
#define MCP_ADDR_ADDR1 34
#define MCP_CS_DATA 5
#define MCP_CS_ADDR0 6
#define MCP_CS_ADDR1 7
// The MCP23S17 is rated for 10MHz, overclock it
// 24Mhz yields highest speeds but was too fast for 1/10 Floopy Drives 
#define SPI_OC0 10 * MHZ
#define SPI_OC1_TESTED 12 * MHZ
#define SPI_OC2_UNSTABLE 24 * MHZ
SPISettings mcpSettings = SPISettings(SPI_OC1_TESTED, MSBFIRST, SPI_MODE0);
MCP23S17 mcpData = MCP23S17(MCP_CS_DATA, MCP_NO_RESET_PIN, MCP_ADDR_DATA);   //Data IO, D0-D15, Address 0x0
MCP23S17 mcpAddr0 = MCP23S17(MCP_CS_ADDR0, MCP_NO_RESET_PIN, MCP_ADDR_ADDR0);  //Address IO, A0-A15, Address 0x1
MCP23S17 mcpAddr1 = MCP23S17(MCP_CS_ADDR1, MCP_NO_RESET_PIN, MCP_ADDR_ADDR1);  //Address and control IO, A16-A21, OE, RAMCE, RAMWE, ROMCE, ROMWE, RESET, Address 0x2

void mcpSetSpiClock(unsigned long clock) {
  mcpSettings = SPISettings(clock, MSBFIRST, SPI_MODE0);
  mcpAddr0.setSPIClockSpeed(clock);
  mcpAddr1.setSPIClockSpeed(clock);
  mcpData.setSPIClockSpeed(clock);
}

// sprintf buffer
char S[USB_BUFSIZE];
// timing operations
unsigned long stopwatch;

// status register
uint16_t SRD;
#define SR(n) bitRead(SRD, n)

#define RED 0xFF0000
#define BLUE 0x0000FF
Adafruit_NeoPixel led(1, 16, NEO_RGB);

inline void ledColor(uint32_t c) {
  led.setPixelColor(0, c);
  led.show();
}

void flashLed(int n, int d = 100) {
  for (int i = 0; i < n; i++) {
    led.setPixelColor(0, 0xff0000);
    led.show();
    delay(d / 2);
    ledColor(0);
    led.show();
    delay(d / 2);
  }
}

// Changing the port mode is superslow so let's cache it
enum DataBusMode { READ,
                   WRITE };
DataBusMode databusMode = WRITE;

inline void ioReadMode(MCP23S17 *mcp) {
  mcp->setPortMode(0, A);
  mcp->setPortMode(0, B);
}

inline void databusReadMode() {
  if (databusMode == READ) return;
  ioReadMode(&mcpData);
  databusMode = READ;
}

inline void ioWriteMode(MCP23S17 *mcp) {
  mcp->setPortMode(0b11111111, A);
  mcp->setPortMode(0b11111111, B);
}

inline void databusWriteMode() {
  if (databusMode == WRITE) return;
  ioWriteMode(&mcpData);
  databusMode = WRITE;
}

// cache address and only set bits that changed
static uint32_t lastAddr = 0;

// NOTE address is in bytes, though we write words
inline void setAddress(uint32_t addr) {
  uint32_t diff = addr ^ lastAddr;

  bool diffA = (diff & 0x000000ff) != 0;
  bool diffB = (diff & 0x0000ff00) != 0;
  if (diffA && diffB) {
    // A0-A15
    mcpAddr0.setPort(addr & 0xff, (addr >> 8) & 0xff);
  } else if (diffA) {
    // A0-A7
    mcpAddr0.setPort(addr & 0xff, A);
  } else if (diffB) {
    // A8-A15
    mcpAddr0.setPort((addr >> 8) & 0xff, B);
  }

  // A16-A21
  if ((diff & 0x00ff0000) != 0) {
    mcpAddr1.setPort((addr >> 16) & 0xff, A);
  }

  lastAddr = addr;
}

// Control pins migrated to io expanders so build a bitmask with these. They're all active low so & these:
const uint8_t IDLE = 0xff;
const uint8_t OE = ~(1 << 0);
const uint8_t RAMCE = ~(1 << 1);
const uint8_t RAMWE = ~(1 << 2);
const uint8_t ROMCE = ~(1 << 3);
const uint8_t ROMWE = ~(1 << 4);
const uint8_t RESET = ~(1 << 5);

// Any bits in bitmask that are 0 will go low (active), bits are 0=OE 1=RAMCE 2=RAMWE 3=ROMCE 4=ROMWE 5=RESET
inline void setControl(uint8_t bitmask = IDLE) {
  static uint8_t lastControl = 0;
  if (bitmask != lastControl) {
    mcpAddr1.setPort(bitmask, B);
  }
  lastControl = bitmask;
}

inline uint16_t readWord() {
  return (mcpData.getPort(B) << 8) | mcpData.getPort(A);
}

inline uint8_t readByte() {
  return mcpData.getPort(A);
}

inline void writeWord(uint32_t addr, uint16_t word) {
  setAddress(addr);
  // In testing, caching last write is slower
  mcpData.setPort(word & 0xff, (word >> 8) & 0xff);
}

inline void writeByte(uint32_t addr, uint8_t byte) {
  setAddress(addr);
  mcpData.setPort(byte, A);
}

// Ensures strings are sent modulo the USB buffer size
// Pass no parameters to use the shared string buffer S (after sprintf for example)
void echo_all(const char *buf = NULL) {
  if (!usb_web.connected()) return;

  if (buf) {
    // A string is provided, this will pad it to buffer size and fill with NUL
    strncpy(S, buf, USB_BUFSIZE);
  }

  usb_web.write(S, USB_BUFSIZE);
  usb_web.flush();

  // if (Serial) {
  //   Serial.write(buf);
  //   Serial.flush();
  // }
}

void echo_ok() {
  echo_all("!OK\r");
}

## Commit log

2025-04-19 Ensure STLs are latest
    [FloopyDrive-Front-MouseEars.stl, FloopyDrive-Rear-MouseEars.stl]
2025-05-10 Kicad file version upgrade
    [flash-32mbit.kicad_pcb, flash-32mbit.kicad_sch]
2025-06-14 Add M29F160 flash to SOP44 maskrom adapter
    [bom.csv, designators.csv, maskrom-adapter.kicad_pcb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]
2025-08-06 Marking SRAM pullup R14 do not populate
    [bom.csv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]
2025-08-31 Using no-support hole printing hack for 0.2mm layer height
    [FloopyDrive-Front.stl, FloopyDrive-Rear.stl]
2025-11-02 Overclocked flash programmer, minor bug fixes
    [flash.ino, pico.ino, zmain_programming.ino]
2025-12-15 Additional delay around switching banks
2025-12-22 1 level of tight loop optimizations
    [flash.ino, pico.ino]
2025-12-22 2 level of tight loop optimizations, modified library
    [flash.ino, pico.ino]
2025-12-22 Revert "Extra level has smaller gains and looks ugly"
    This reverts commit ccc753b9b335a220da13636d59e9ca2c5a8f6ecf.
    [flash.ino]
2025-12-22 Localized mods allow reverting library, custom OC command
    [flash.ino, pico.ino, zmain_programming.ino]
2025-12-22 Idle no longer deasserts ROMCE
    [flash.ino, pico.ino, zmain_programming.ino]
2025-12-22 Fix repolling of multi byte write, end-of-block shenanigans no longer necessary
    [flash.ino]
2026-05-30 Ensuring shell files are latest
    [FloopyDrive-Front-MouseEars.stl, FloopyDrive-Front.3mf, FloopyDrive-Front.stl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]
